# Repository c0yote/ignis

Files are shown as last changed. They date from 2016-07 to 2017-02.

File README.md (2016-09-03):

# ignis

ignis is a graph controllable electric oven, control board, and software interface for foundry work, heat treating steel, and reflow soldering printed circuit boards.

The project is completely open source and open hardware.  All hardware design artifacts are licensed under a Creative Commons license and all software and firmware under the MIT License.

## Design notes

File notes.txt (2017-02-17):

https://www.youtube.com/watch?v=ztXRjyCQxlE
http://electronics.stackexchange.com/questions/41938/230v-ac-to-5v-dc-converter-lossless

Add a manufacturing note that the design is assuming a 2 oz/ft2 trace

Update Notes:
1. Consider Changing P? from a screw 
terminal to a dedicated thermocouple 
connector like a PCC-SMP-K.

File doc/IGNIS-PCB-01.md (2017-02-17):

## Hardware Design Notes

### Thermocouple Interface Circuit

A MAX31855 IC reads a K type thermocouple and passed the temperature out over SPI.  Level conversion is accomplished via a resistor divider.

The MAX31855 series has other units that can interpret other thermocouple types.  Substitution here should require  minimal effort if a different type  thermocouple is necessary.
 
### Load Switch Circuit

Random phase TRIAC output optocoupler uses hi signal to trip a TRIAC.  No on board over-current protection other than an inline safety port.

### Zero-Cross Detection Circuit

This is the zero cross detection circuit. It will spike low when the AC crosses zero.

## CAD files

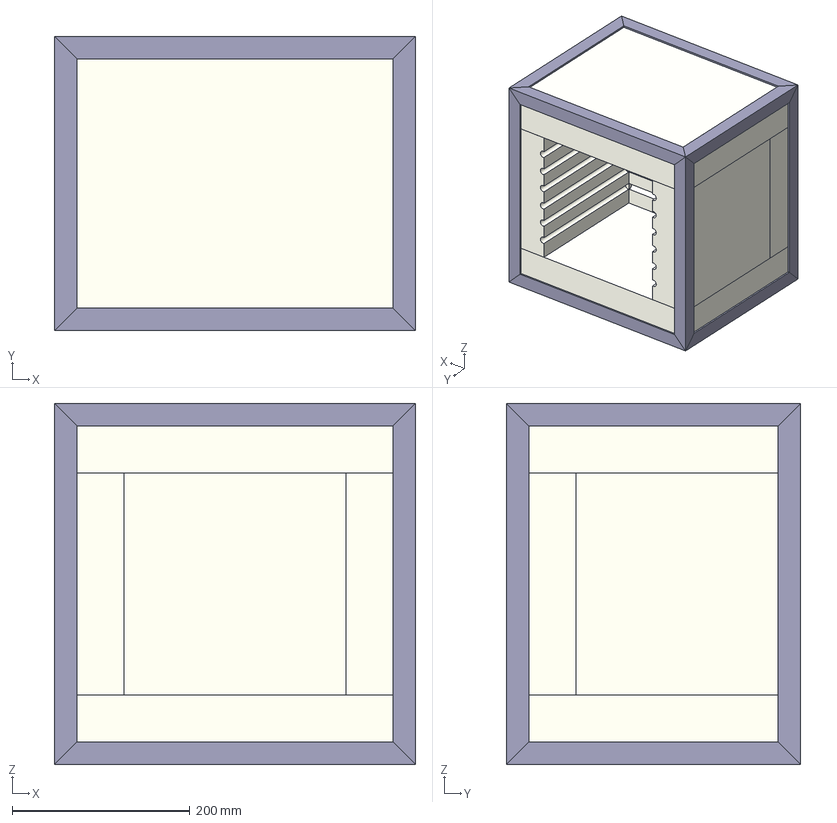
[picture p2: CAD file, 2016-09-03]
parts/ignis-assembly.FCStd
406.4 x 331.4 x 406.4 mm
wall-left
wall-back
wall-right
cap-top
cap-bottom
corner-right
corner-left
frame-short000
frame-short001
frame-short002
frame-short003
frame-long000
frame-long001
frame-long002
frame-long003
frame-long004
frame-long005
frame-long006
frame-long007

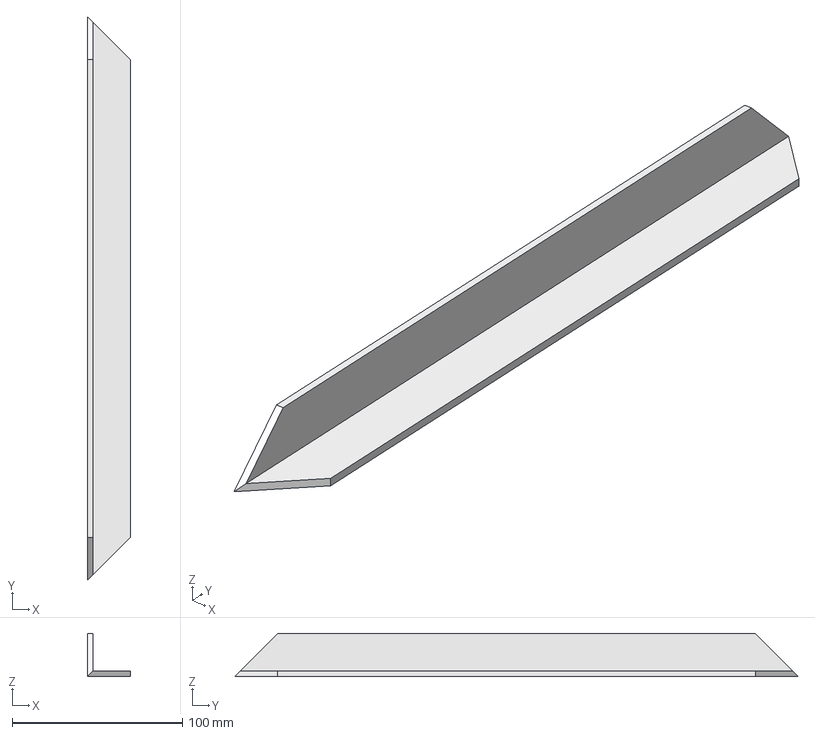
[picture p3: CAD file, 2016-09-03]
parts/frame-segment-short.step
25.4 x 331.4 x 25.4 mm

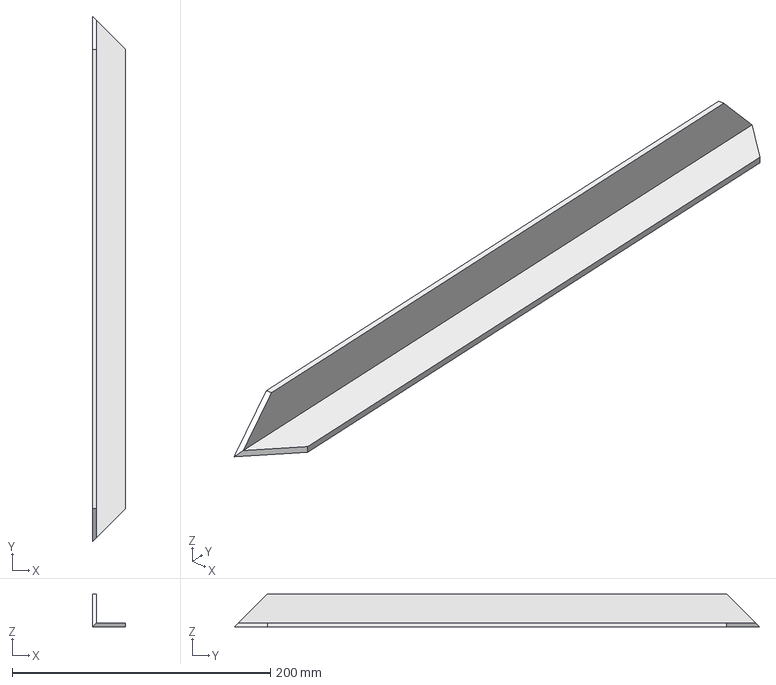
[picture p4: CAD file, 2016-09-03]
parts/frame-segment-long.step
25.4 x 406.4 x 25.4 mm

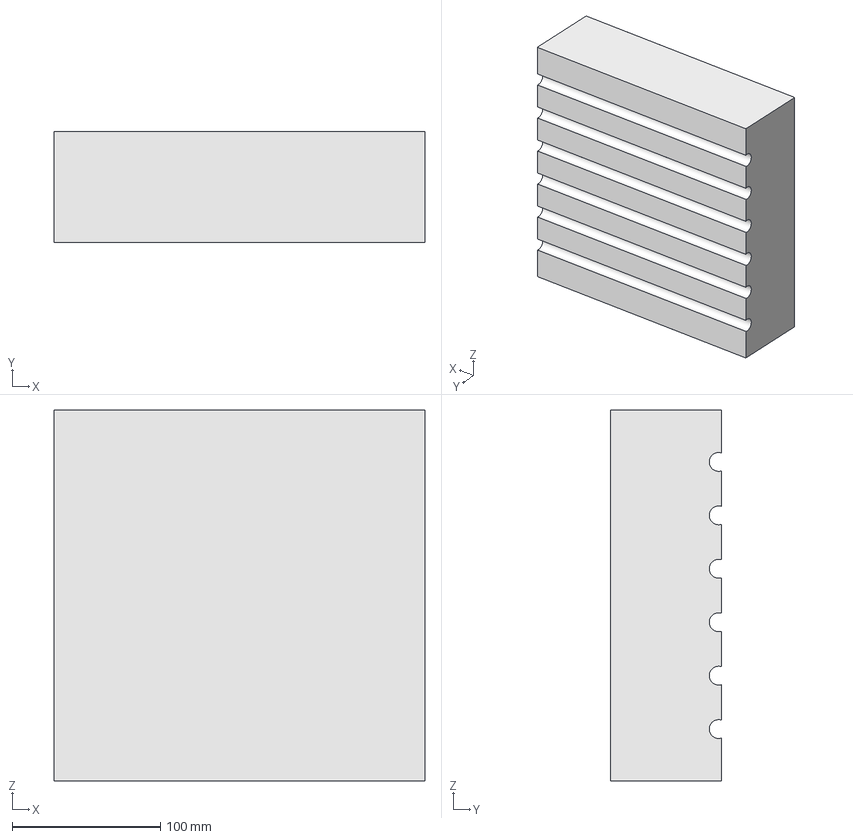
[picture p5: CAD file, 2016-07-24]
parts/insulating-wall.step
250.0 x 75.0 x 250.0 mm

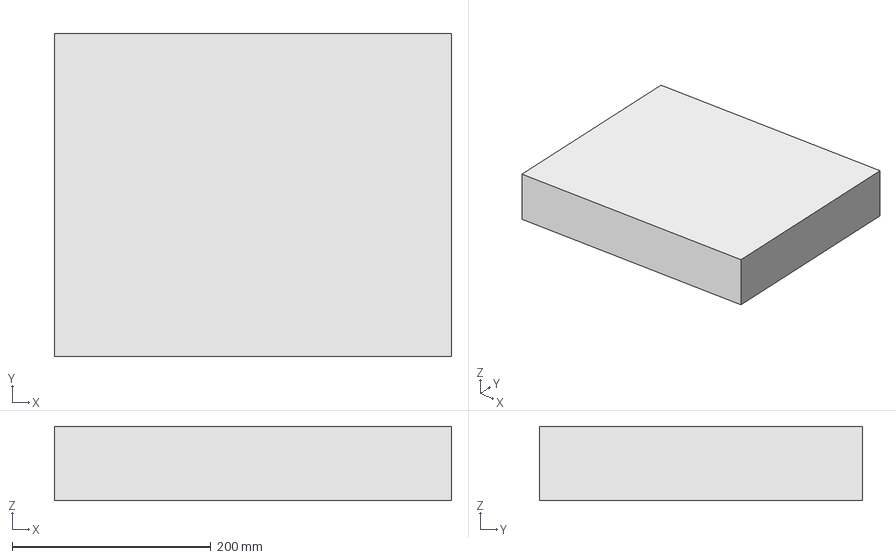
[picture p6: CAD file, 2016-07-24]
parts/insulating-cap.step
400.0 x 325.0 x 75.0 mm

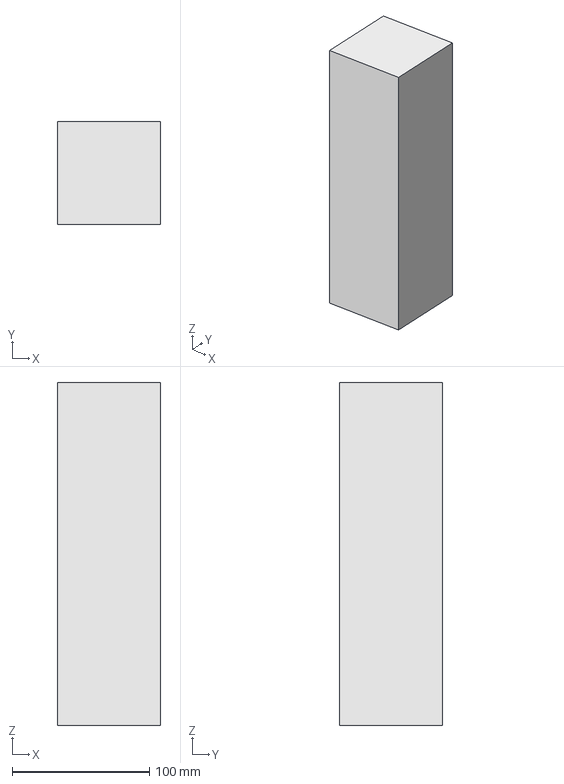
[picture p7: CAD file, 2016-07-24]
parts/insulating-corner.step
75.0 x 75.0 x 250.0 mm

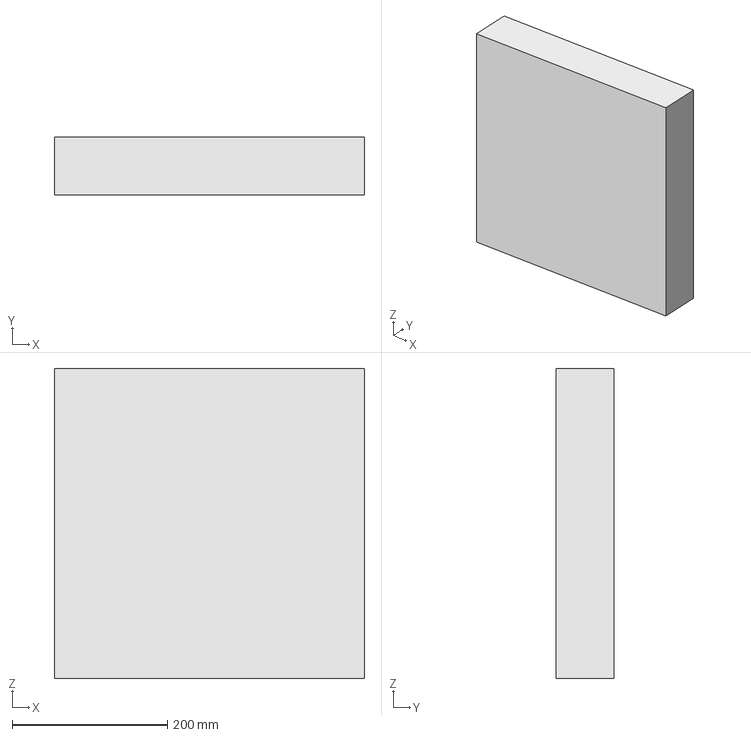
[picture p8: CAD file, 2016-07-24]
parts/insulating-door.step
400.0 x 75.0 x 400.0 mm

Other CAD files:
parts/insulating-cap-wall.step
parts/frame-segment-long.FCStd
parts/frame-segment-short.FCStd
parts/insulating-cap.FCStd
parts/insulating-corner.FCStd
parts/insulating-door.FCStd
parts/insulating-wall.FCStd

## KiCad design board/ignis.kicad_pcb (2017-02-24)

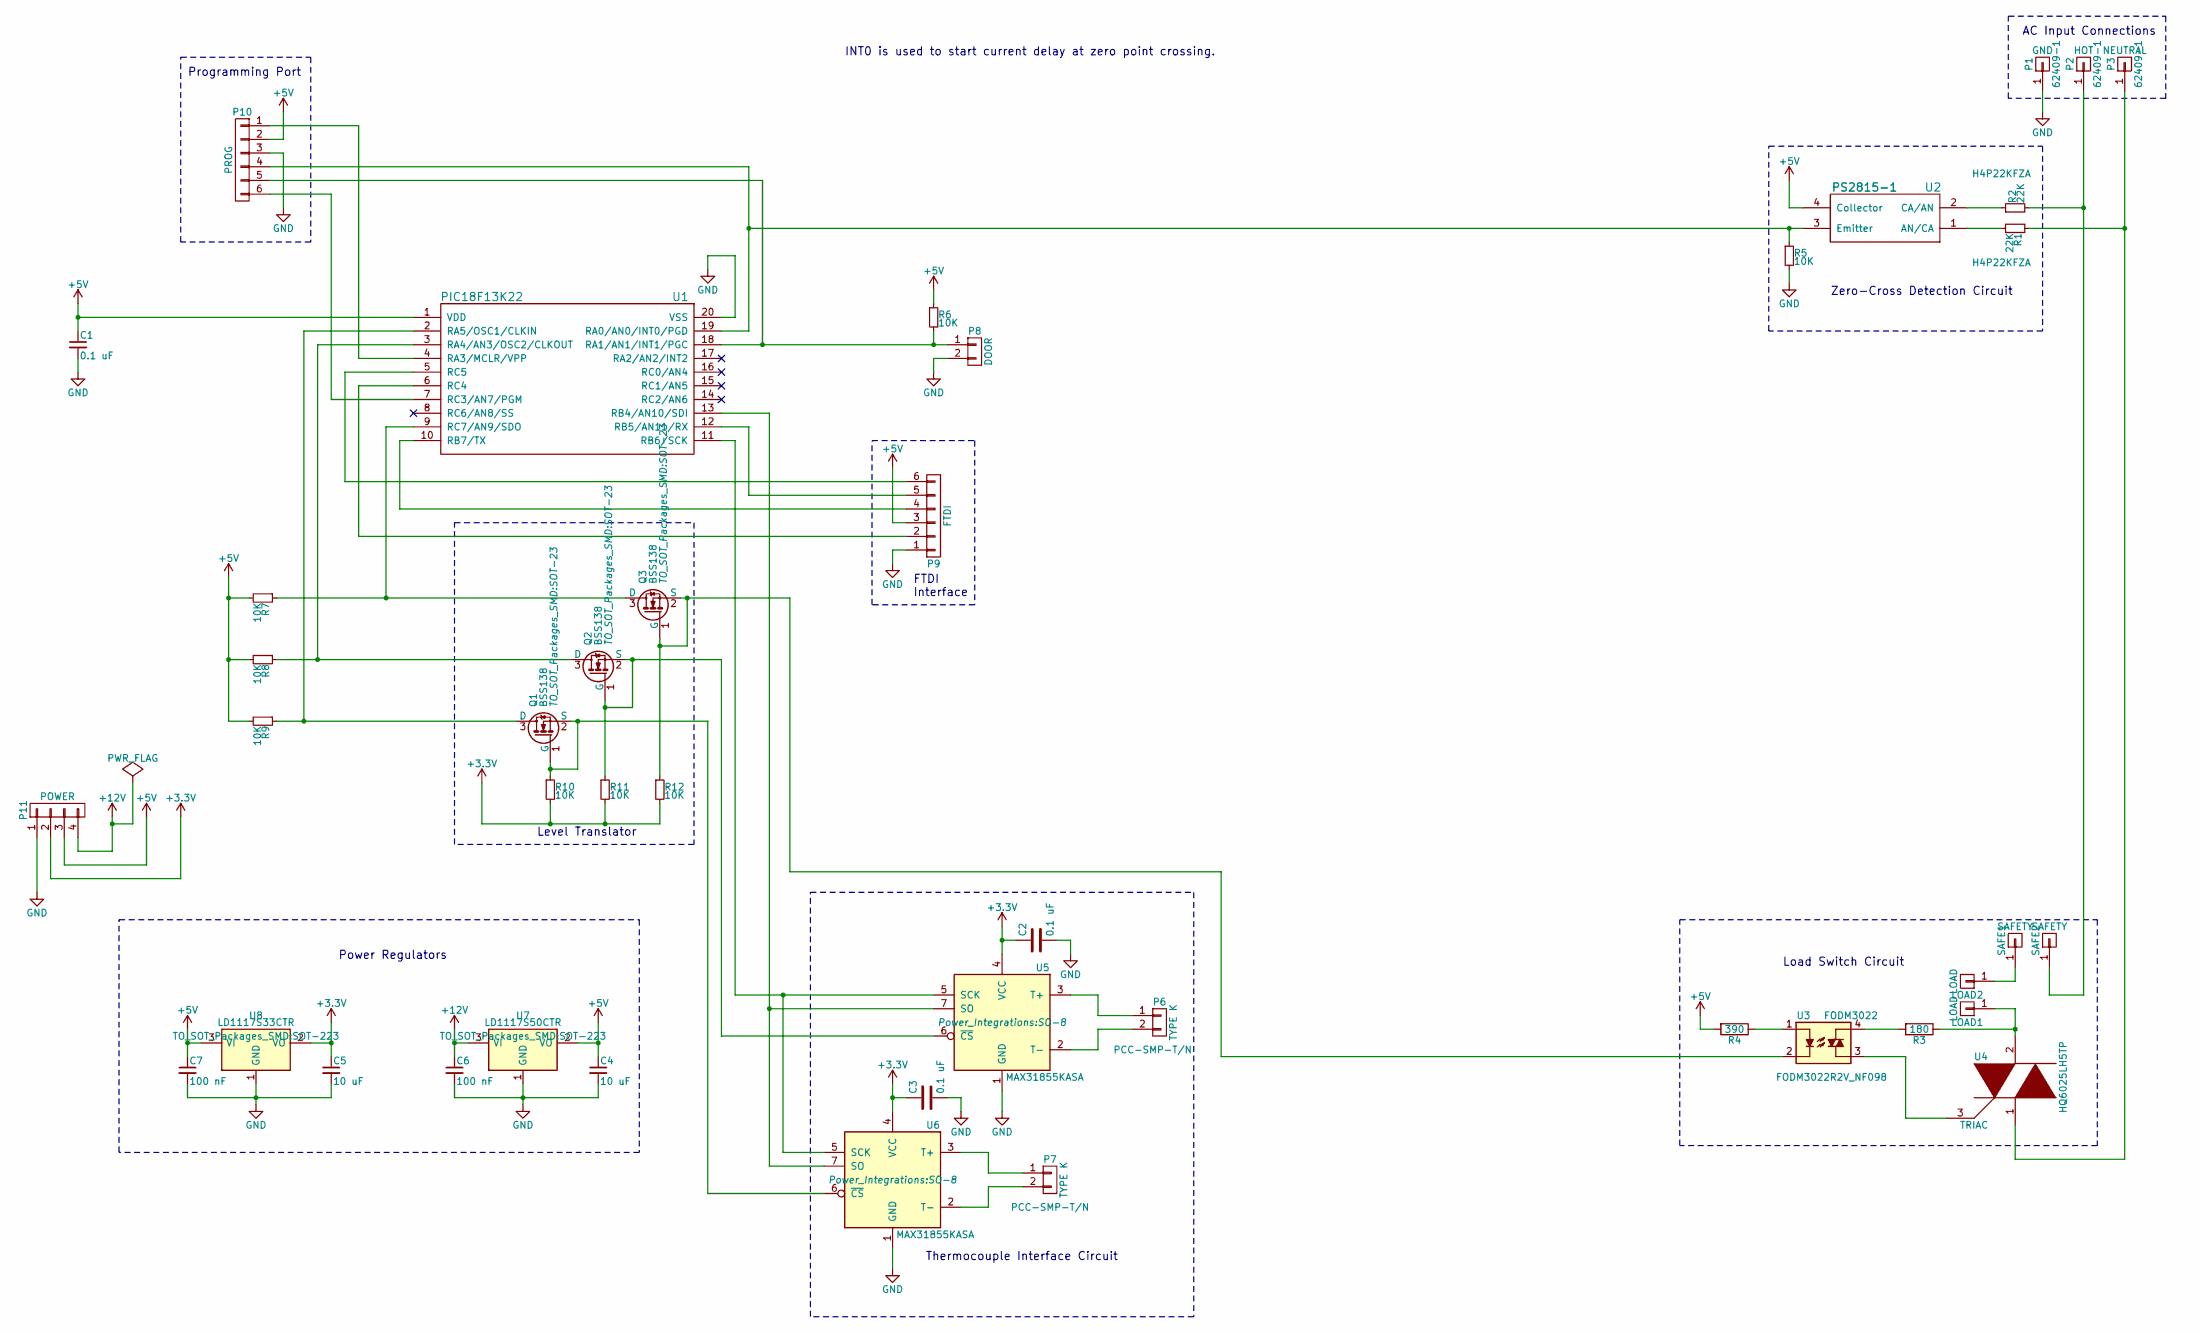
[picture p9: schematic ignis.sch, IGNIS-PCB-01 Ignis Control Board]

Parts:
C1, C2, C3: 0.1 uF; C_0603
C4, C5: 10 uF; C_0603
C6, C7: 100 nF; C_0603
LOAD1, LOAD2: LOAD; 62409-1
P1: GND; 62409-1
P2: HOT; 62409-1
P3: NEUTRAL; 62409-1
P6, P7: TYPE K; PCC-SMP-TN
P8: DOOR; TerminalBlock_Pheonix_MPT-2.54mm_2pol
P9: FTDI; PINHEAD1-6
P10: PROG; Pin_Header_Straight_1x06
P11: POWER; TerminalBlock_Pheonix_MPT-2.54mm_4pol
Q1, Q2, Q3: BSS138; SOT-23
R1, R2: 22K; R_0603
R3: 180; R_0603
R4: 390; R_0603
R5, R6, R7, R8, R9, R10, R11, R12: 10K; R_0603
SAFE1, SAFE2: SAFETY; 62409-1
U1: PIC18F13K22; SSOP-20
U2: PS2815-1
U3: FODM3022; FODM30XX
U4: TRIAC; TO-220_Neutral123_Horizontal_LargePads
U5, U6: MAX31855KASA; SO-8
U7: LD1117S50CTR; SOT-223
U8: LD1117S33CTR; SOT-223

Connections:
+3V3: C2.1, C3.1, C5.1, P11.2, R10.2, R11.2, R12.2, U5.4 (VCC), U6.4 (VCC), U8.2 (VO)
+5V: C1.1, C4.1, C7.1, P9.3, P10.2, P11.3, R4.2, R6.1, R7.2, R8.2, R9.2, U1.1 (VDD), U2.4 (Collector), U7.2 (VO), U8.3 (VI)
+12V: C6.1, P11.4, U7.3 (VI)
GND: C1.2, C2.2, C3.2, C4.2, C5.2, C6.2, C7.2, P1.1, P8.2, P9.1, P10.3, P11.1, R5.2, U1.20 (VSS), U5.1 (GND), U6.1 (GND), U7.1 (GND), U8.1 (GND)
unnamed: LOAD1.1, R3.1, U4.2
unnamed: LOAD2.1, SAFE1.1
unnamed: P2.1, R2.2, SAFE2.1
unnamed: P3.1, R1.1, U4.1
unnamed: P6.1, U5.3 (T+)
unnamed: P6.2, U5.2 (T-)
unnamed: P7.1, U6.3 (T+)
unnamed: P7.2, U6.2 (T-)
unnamed: P9.2, U1.6 (RC4)
unnamed: P9.4, U1.10 (RB7/TX)
unnamed: P9.5, U1.12 (RB5/AN11/RX)
unnamed: P9.6, U1.5 (RC5)
unnamed: P10.1, U1.4 (RA3/MCLR/VPP)
unnamed: P10.4, R5.1, U1.19 (RA0/AN0/INT0/PGD), U2.3 (Emitter)
unnamed: P8.1, P10.5, R6.2, U1.18 (RA1/AN1/INT1/PGC)
unnamed: P10.6, U1.7 (RC3/AN7/PGM)
unnamed: Q1.1 (G), Q1.2 (S), R10.1, U6.6 (~CS~)
unnamed: Q1.3 (D), R9.1, U1.2 (RA5/OSC1/CLKIN)
unnamed: Q2.1 (G), Q2.2 (S), R11.1, U5.6 (~CS~)
unnamed: Q2.3 (D), R8.1, U1.3 (RA4/AN3/OSC2/CLKOUT)
unnamed: Q3.1 (G), Q3.2 (S), R12.1, U3.2
unnamed: Q3.3 (D), R7.1, U1.9 (RC7/AN9/SDO)
unnamed: R1.2, U2.1 (AN/CA)
unnamed: R2.1, U2.2 (CA/AN)
unnamed: R3.2, U3.4
unnamed: R4.1, U3.1
unnamed: U1.11 (RB6/SCK), U5.5 (SCK), U6.5 (SCK)
unnamed: U1.13 (RB4/AN10/SDI), U5.7 (SO), U6.7 (SO)
unnamed: U3.3, U4.3

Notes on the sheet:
INT0 is used to start current delay at zero point crossing.
AC Input Connections
Thermocouple Interface Circuit
Load Switch Circuit
Zero-Cross Detection Circuit
Programming Port
FTDI Interface
Level Translator
Power Regulators

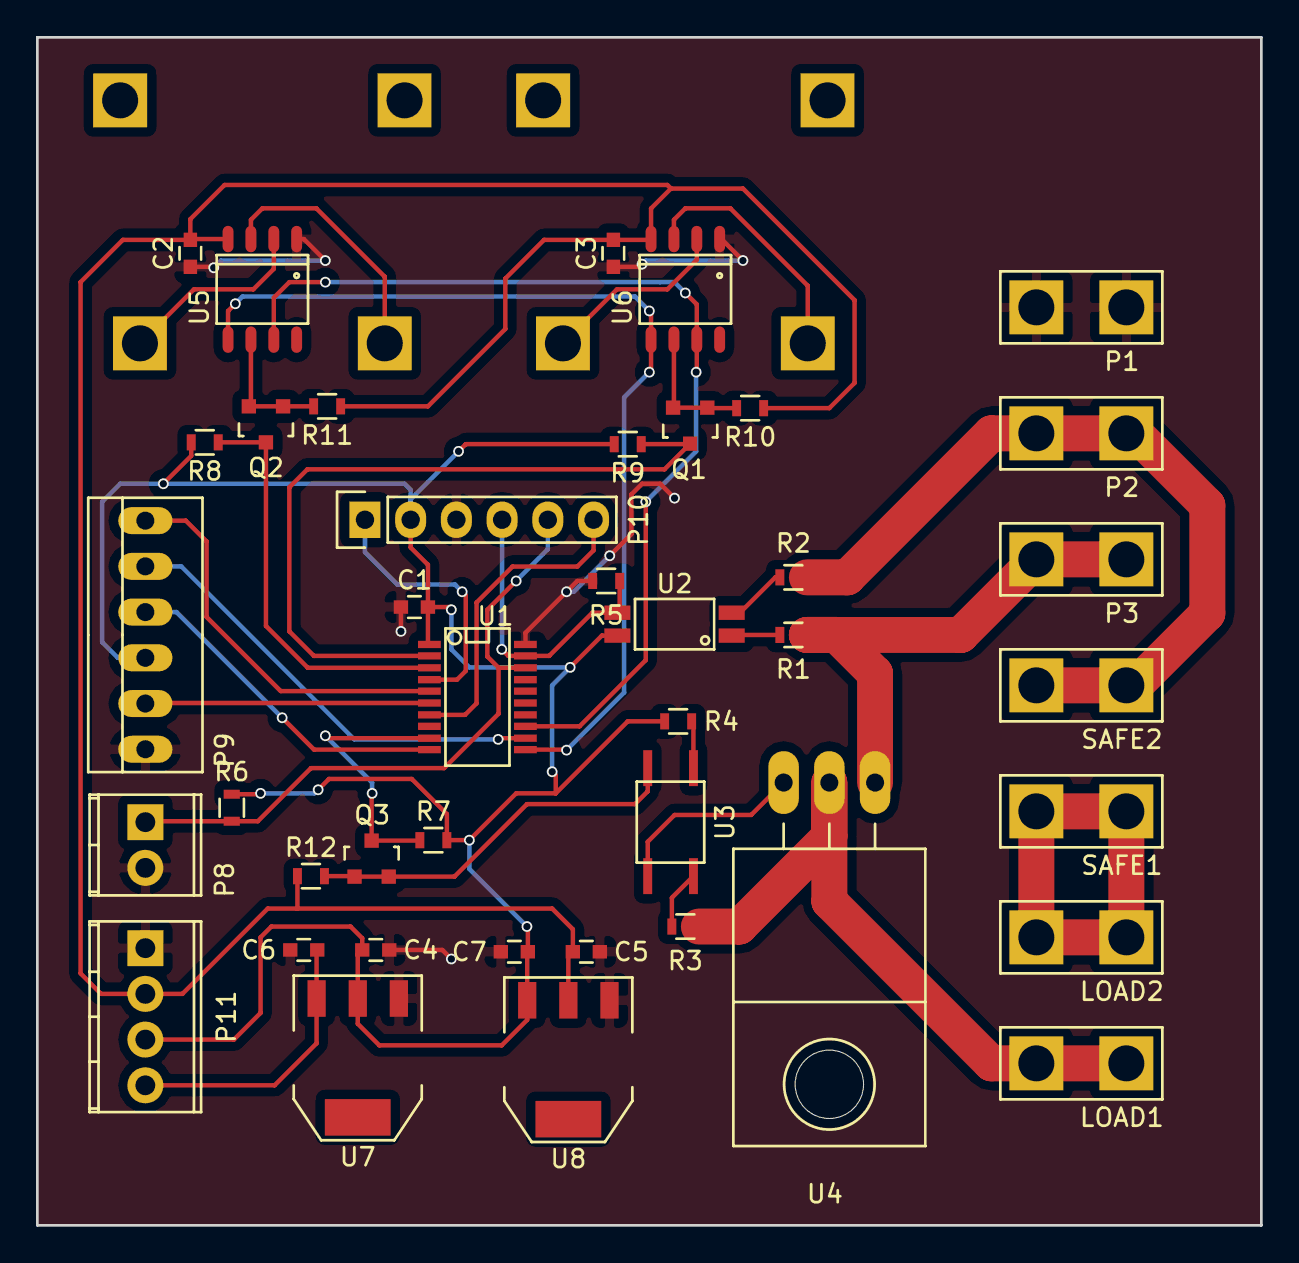
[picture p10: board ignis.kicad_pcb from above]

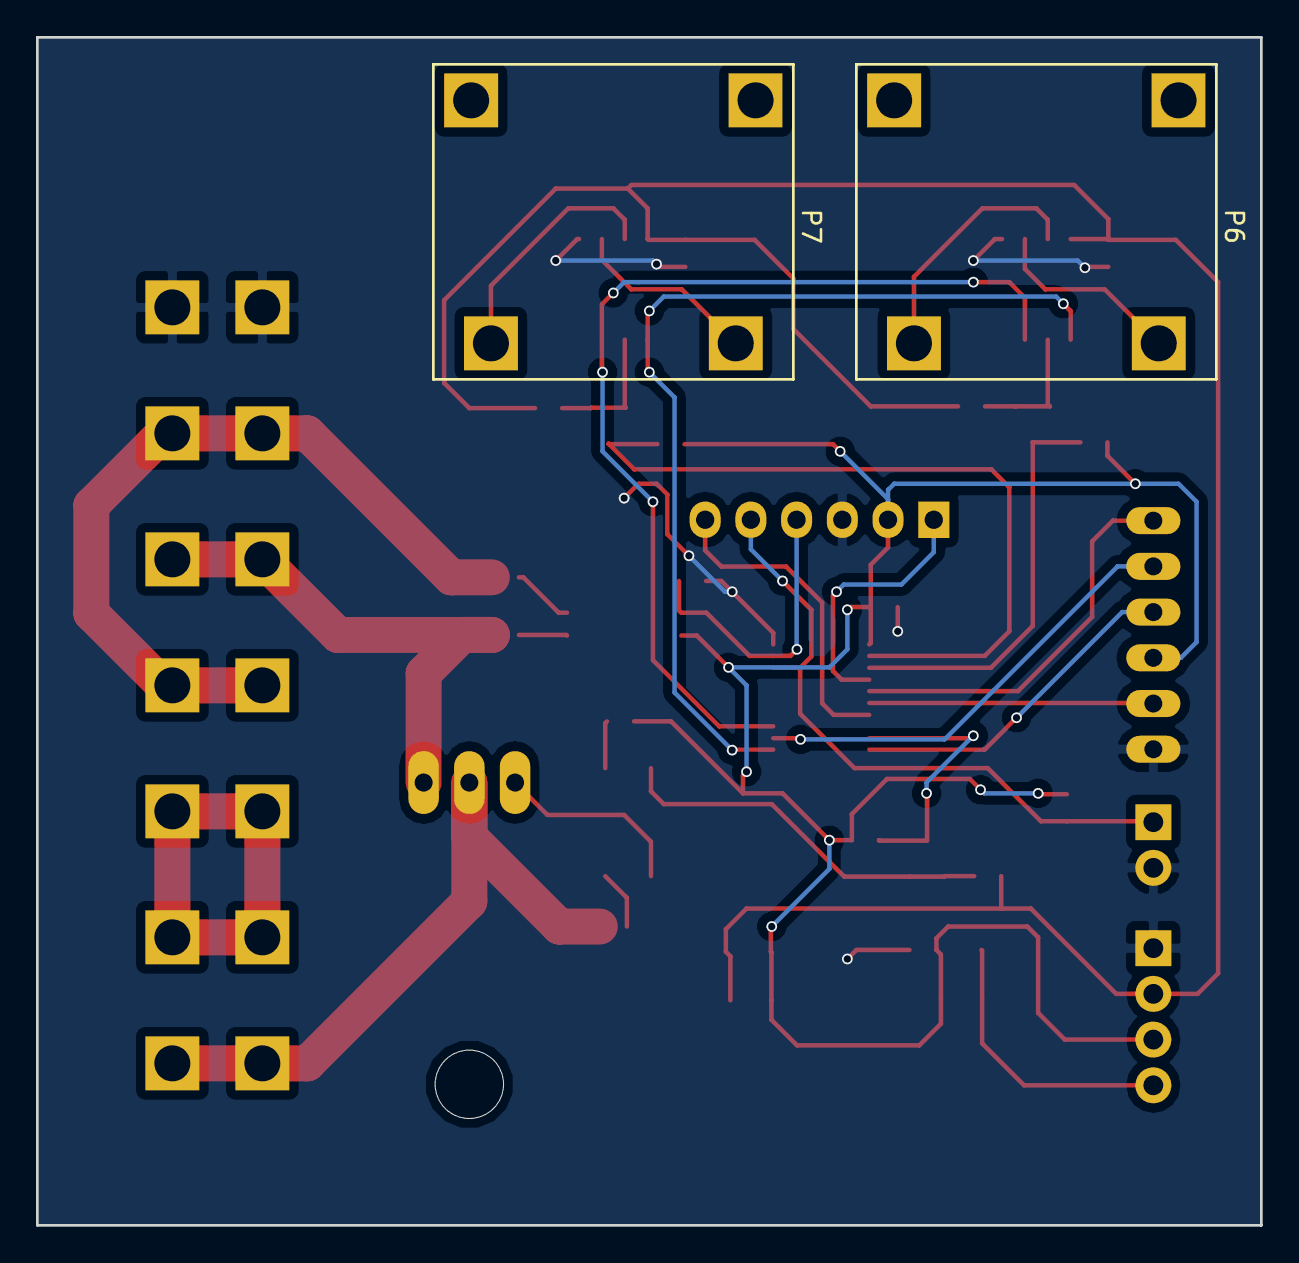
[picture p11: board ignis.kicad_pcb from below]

Board: 2 copper layers, 68.0 x 66.0 mm, 43 parts (2 on the bottom side), 33 nets.

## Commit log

2016-07-18 Initial commit.
    [ignis-assembly.FCStd, ignis.kicad_pcb, ignis.sch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]
2016-07-24 Revised insulation plan.
    [ignis-assembly.FCStd, ignis.sch, insulating-back-wall.FCStd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]
2016-09-03 Finalized the Zero-Cross circuit via experimentation.
    [ignis.sch]
2016-09-03 TRIAC control circuit.
    [ignis.sch]
2016-09-03 Draft of a body frame CADs.
    [frame-segment-long.FCStd, frame-segment-long.step, frame-segment-short.FCStd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]
2017-02-17 Layout done for Rev. 0 bench test board.
    [ignis.kicad_pcb, ignis.sch]
2017-02-24 Edge fix and plot for prototype.
    [board.GBL, board.GBO, board.GBS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]

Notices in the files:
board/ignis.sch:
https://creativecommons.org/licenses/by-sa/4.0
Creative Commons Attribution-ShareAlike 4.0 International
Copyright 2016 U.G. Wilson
